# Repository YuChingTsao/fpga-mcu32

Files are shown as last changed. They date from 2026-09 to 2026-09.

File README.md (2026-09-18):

# FPGA MCU32 - AVR-Class Microcontroller on a DE10-Lite

A custom **32-bit fixed-cycle soft microcontroller implemented in VHDL** on an Intel MAX 10 FPGA. The design integrates a multi-cycle CPU, program/data memory, a memory-mapped bus, GPIO, timer, hardware PWM, prioritized interrupts, and dedicated timing/debug instrumentation.

**Capstone project - University of Windsor, Electrical & Computer Engineering (2026)**  
**Team:** Kazi Masrur Rahman and Yu Ching Tsao  
**Target hardware:** Terasic DE10-Lite / Intel MAX 10 (`10M50DAF484C7G`)

> The project uses an Arduino/ATmega328P-class board as a timing comparison baseline. “AVR-class” describes the embedded-control use case and comparison target; the custom MCU is not AVR instruction-set compatible.

## Project Highlights

- Designed a **32-bit multi-cycle CPU** with 16 general-purpose 32-bit registers and fixed 32-bit instructions.
- Built separate **1024 x 32-bit program ROM and data RAM** with a 32-bit memory-mapped interconnect.
- Implemented **GPIO, 32-bit timer, PWM, interrupt controller, and measurement/debug peripherals** in VHDL.
- Added self-checking verification across **18 VHDL testbenches**, from individual units through integrated CPU/peripheral behavior.
- Closed timing at **50 MHz** on the DE10-Lite with positive setup and hold slack.
- Measured an **FPGA request-to-GPIO response of 334 ns** using oscilloscope edge-crossing measurements.
- Demonstrated hardware PWM at **2.500 kHz and 25% duty cycle** using a 20,000-count period and 5,000-count duty setting.
- Exposed interrupt request, acknowledgement, ISR entry, PWM, and GPIO response through dedicated debug signals for Signal Tap and oscilloscope validation.

## Architecture

The system uses a Harvard-style memory organization and a common 32-bit memory-mapped peripheral bus.

| Block | Implementation |
|---|---|
| CPU | 32-bit multi-cycle FSM core |
| Register file | 16 x 32-bit registers |
| Instruction format | Fixed 32-bit |
| Program memory | 1024 x 32-bit ROM |
| Data memory | 1024 x 32-bit RAM |
| Bus | 32-bit memory-mapped interconnect |
| Peripherals | GPIO, timer, PWM, interrupt controller, measurement/debug |
| Clock | 50 MHz |
| FPGA | Intel MAX 10 on DE10-Lite |

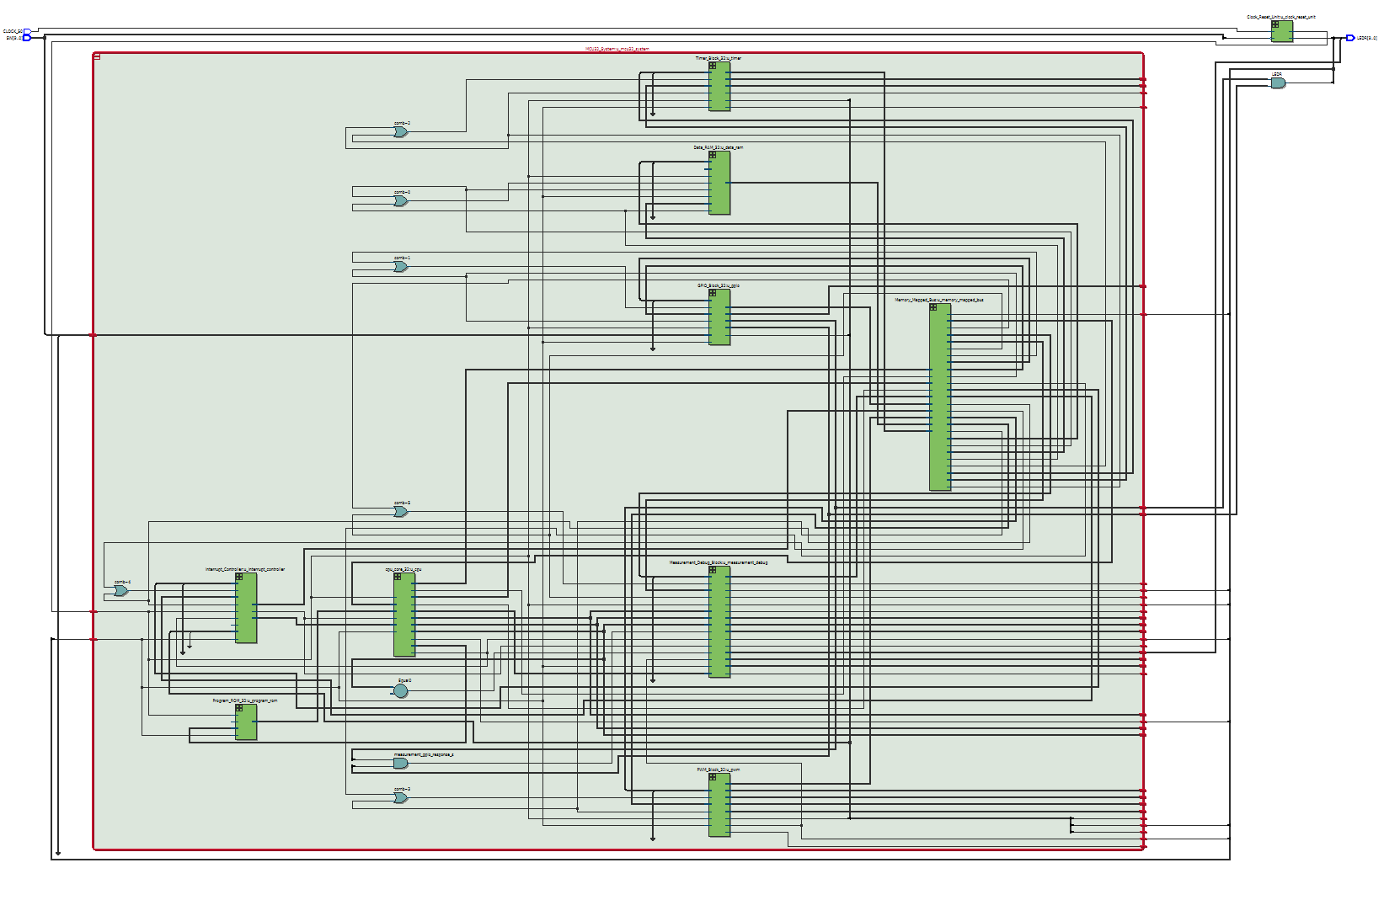
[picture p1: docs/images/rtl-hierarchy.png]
Quartus RTL hierarchy


## Memory Map

| Address range | Target |
|---|---|
| `0x00000000 - 0x00000FFF` | Data RAM |
| `0x40000000 - 0x4000001F` | GPIO |
| `0x40000020 - 0x4000003F` | Timer |
| `0x40000040 - 0x4000005F` | PWM |
| `0x40000060 - 0x4000007F` | Interrupt controller |
| `0x40000080 - 0x4000009F` | Measurement/debug |

Unmapped or invalid reads return `0xDEADBEEF` as a recognizable bus diagnostic value.

## Measured Results

### Interrupt response

The FPGA timing path was instrumented so the request and resulting GPIO response could be observed directly.

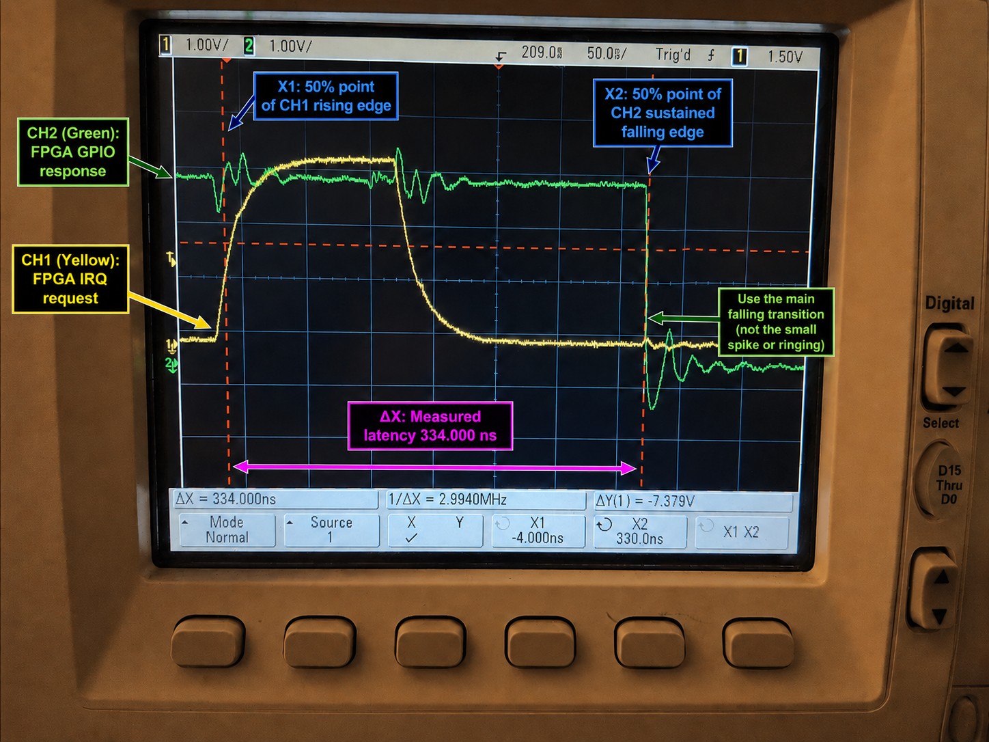
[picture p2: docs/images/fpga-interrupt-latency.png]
FPGA interrupt latency capture


Measured request-to-GPIO response: **334 ns**.

For the Arduino Nano-class comparison, the corresponding marker-to-ISR GPIO response capture measured **1.170 us** under the defined experiment endpoints.

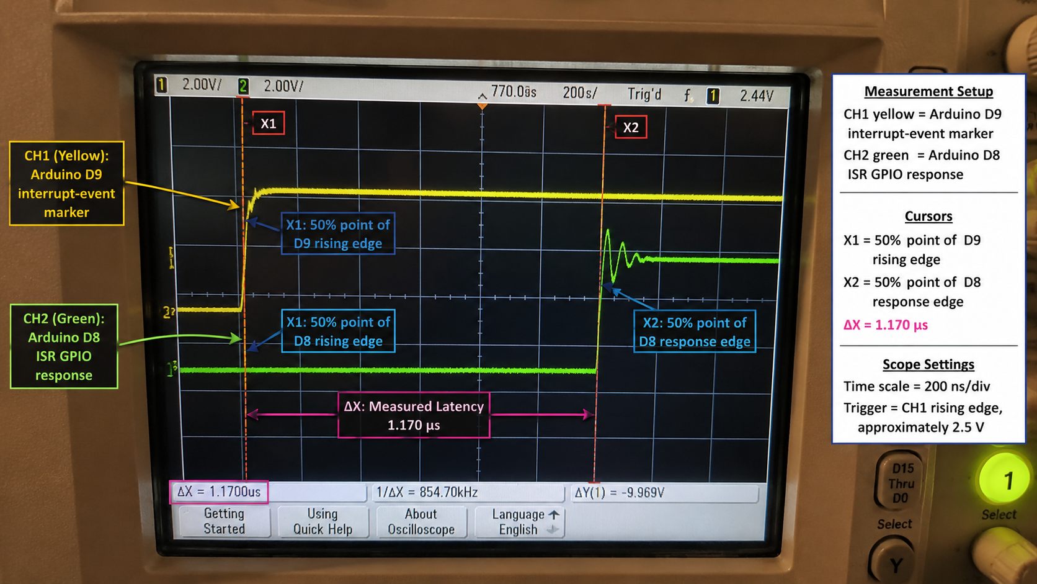
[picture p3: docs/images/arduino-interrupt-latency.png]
Arduino interrupt latency capture


The measurements use different internal visibility because the FPGA exposes controller-level events that are not externally accessible on the commercial MCU; the comparison is therefore presented as an experimental timing baseline rather than a universal platform-performance claim.

### PWM

The hardware PWM counter operates independently of CPU instruction execution. With a 50 MHz clock, `PERIOD = 20000` and `DUTY = 5000` produce a nominal 400 us period, 100 us high time, **2.500 kHz**, and **25% duty cycle**.

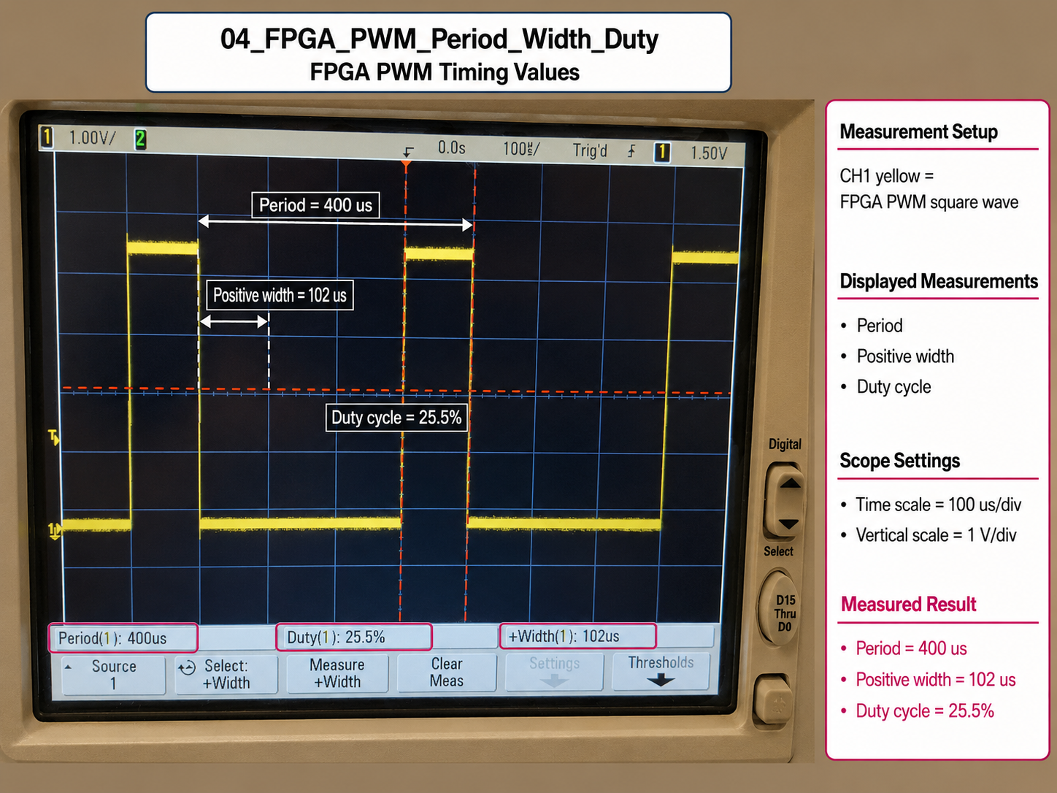
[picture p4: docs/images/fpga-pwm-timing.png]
FPGA PWM timing capture


## Verification

Verification was performed progressively:

1. Unit-level self-checking VHDL testbenches for the ALU, register file, memories, bus logic, GPIO, timer, PWM, interrupt controller, and measurement block.
2. CPU + memory and CPU + peripheral integration tests.
3. Full interrupt/ISR and firmware-driven system simulations.
4. Quartus synthesis, fitting, and static timing analysis at 50 MHz.
5. DE10-Lite LED-based hardware tests.
6. Intel Signal Tap observation of internal timing events.
7. Oscilloscope validation of interrupt response and PWM timing.

See [`docs/verification.md`](docs/verification.md) for the testbench inventory and validation flow.

## My Documented Contributions - Kazi Masrur Rahman

This was a two-person capstone project. My documented technical contributions included:

- Memory organization and the memory-mapped bus architecture.
- GPIO, timer, and PWM peripheral design/integration.
- Program/data memory integration and demonstration firmware configuration.
- DE10-Lite top-level integration, board I/O mapping, debug/probe outputs, and timing constraints.
- Shared work on interrupt/measurement integration and system-level validation.
- FPGA resource/timing analysis and laboratory measurement of interrupt/PWM behavior.
- Technical documentation and presentation of the implemented architecture and measured results.

The CPU core and other project elements were developed collaboratively with my teammate; this repository is presented as a portfolio record of the team project rather than as a claim of sole authorship.

## Repository Structure

```text
fpga-mcu32/
├── src/                  # Synthesizable VHDL
│   ├── bus/
│   ├── common/
│   ├── cpu/
│   ├── debug/
│   ├── memory/
│   ├── peripherals/
│   └── top/
├── testbench/            # Self-checking VHDL testbenches
├── quartus/              # Quartus project + timing constraints
├── debug/                # Signal Tap configurations
├── docs/                 # Architecture, verification, images, poster
└── scripts/              # Simulation helper
```

## Build in Quartus Prime

The original project was developed with **Quartus Prime 25.1 Standard**.

1. Clone the repository.
2. Open `quartus/MCU32_Project.qpf` in Quartus Prime.
3. Select the `top_level_de10_lite` revision if required.
4. Run **Analysis & Synthesis** or **Start Compilation**.
5. Program the DE10-Lite using the generated programming file.

The QSF references the VHDL source tree using paths relative to the `quartus/` directory, so the repository structure should be kept intact.

## Simulating with Questa / ModelSim

From the repository root, start Questa/ModelSim and run:

```tcl
do scripts/questa_compile.do
vsim work.tb_alu32
run -all
```

Replace `tb_alu32` with another entity from the `testbench/` directory. Integrated testbenches are listed in [`docs/verification.md`](docs/verification.md).

## Documentation

- [Architecture notes](docs/architecture.md)
- [Verification and validation](docs/verification.md)
- [Capstone poster](docs/poster/Team29_Poster.pdf)

## Tools & Skills Demonstrated

**VHDL · FPGA Design · Intel Quartus Prime · Questa/ModelSim · Digital Logic · Computer Architecture · Memory-Mapped I/O · Interrupts · PWM · Static Timing Analysis · Signal Tap · Oscilloscope Measurement · Hardware Verification**

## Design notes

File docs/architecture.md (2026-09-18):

# Architecture Notes

## CPU

The MCU32 processor is a custom 32-bit multi-cycle finite-state-machine CPU. Instructions move through explicit fetch, decode, execute, memory, and write-back states. Interrupt entry is accepted at instruction boundaries so the response path can be reasoned about and measured cycle-by-cycle.

The design uses 16 x 32-bit general-purpose registers, condition/status flags, a program counter, instruction register, saved return PC, and fixed 32-bit instructions.

## Memory Organization

Program and data storage are separated:

- Program ROM: 1024 x 32-bit words.
- Data RAM: 1024 x 32-bit words (4 KiB byte-addressed range).

This allows program fetches to remain separate from data/peripheral transactions.

## Memory-Mapped Interconnect

The 32-bit bus is split into one data-memory range and five peripheral windows. The interconnect contains:

- Address decoder.
- One-hot write-enable decoder.
- Read-data multiplexer.
- Default response / error handling.
- Word-alignment checking.

Invalid or unmapped reads return `0xDEADBEEF`.

## Peripherals

### GPIO

Provides synchronized input sampling, direction/output registers, rising/falling edge detection, interrupt enables, and sticky interrupt status.

### Timer

A 32-bit counter with prescaler, compare, control, and status registers. Compare and overflow events can generate interrupt requests.

### PWM

A dedicated hardware counter produces PWM independently of CPU execution. The demonstration configuration uses a 20,000-count period and 5,000-count high interval at 50 MHz.

### Interrupt Controller

Four sources are synchronized and edge-captured into pending bits. A fixed-priority policy selects the active source and produces a vector address. The controller exposes status and debug information to software and the measurement subsystem.

### Measurement / Debug

Dedicated counters and probe signals expose interrupt request, acknowledgement, ISR entry, GPIO response, and PWM timing. These signals were used in simulation, Signal Tap, and oscilloscope measurements.

## Board Integration

The top level maps the design to the DE10-Lite's 50 MHz clock, switches, red LEDs, and GPIO expansion pins. External switch inputs are synchronized internally. Timing constraints exclude asynchronous observation/input paths while constraining the internal 50 MHz clocked design.

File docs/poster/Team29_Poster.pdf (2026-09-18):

# Team 29: Design and Implementation of an AVR-Class Microcontroller on an FPGA

Commercial microcontrollers are inexpensive and easy to program, but their internal real-time timing path is largely fixed by the vendor. This project develops a 32-bit fixed-cycle microcontroller in VHDL for the DE10-Lite FPGA. The design combines a multi-cycle finite-state machine, sixteen 32-bit registers, fixed 32-bit instructions, separate program and data memories, and a 32-bit memory-mapped bus. GPIO, a 32-bit timer, hardware PWM, and a prioritized interrupt controller are integrated as on-chip peripherals. Dedicated probe pins expose interrupt request, acknowledge, ISR entry, GPIO response, and PWM timing. The contribution is a transparent and measurable real-time control platform rather than a claim that FPGAs are universally superior to MCUs.

### Department: Electrical and Computer Engineering Capstone 2026

### Kazi Masrur Rahman and Yu Ching Tsao Advisor: Dr. Roberto Muscedere

### INTRODUCTION & OBJECTIVE

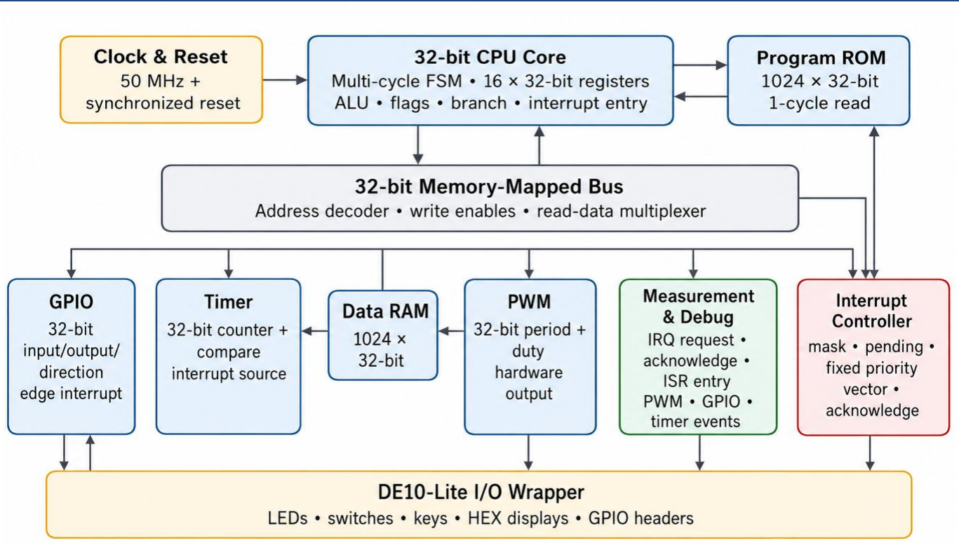
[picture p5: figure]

### METHODOLOGY

### INTERRUPT TIMING TRACE

ABSTRACT | DESIGN OVERVIEW | RESULTS & TIMING COMPARISON

A soft-core processor is described in hardware description language, customized for an application, and synthesized into programmable logic [1]. This makes the complete control path visible from the register-transfer level to a physical output pin. The project asks whether a deliberately simple FPGA microcontroller can provide a shorter, bounded, and easier-toaudit request-to-response path than an Arduino Nano-class MCU while remaining understandable to students. Objective: Design, simulate, implement, and measure the FPGA MCU, then compare its digital I/O timing with an ATmega328P-class system using identical trigger and response definitions.

### Implementation and Comparison Platform

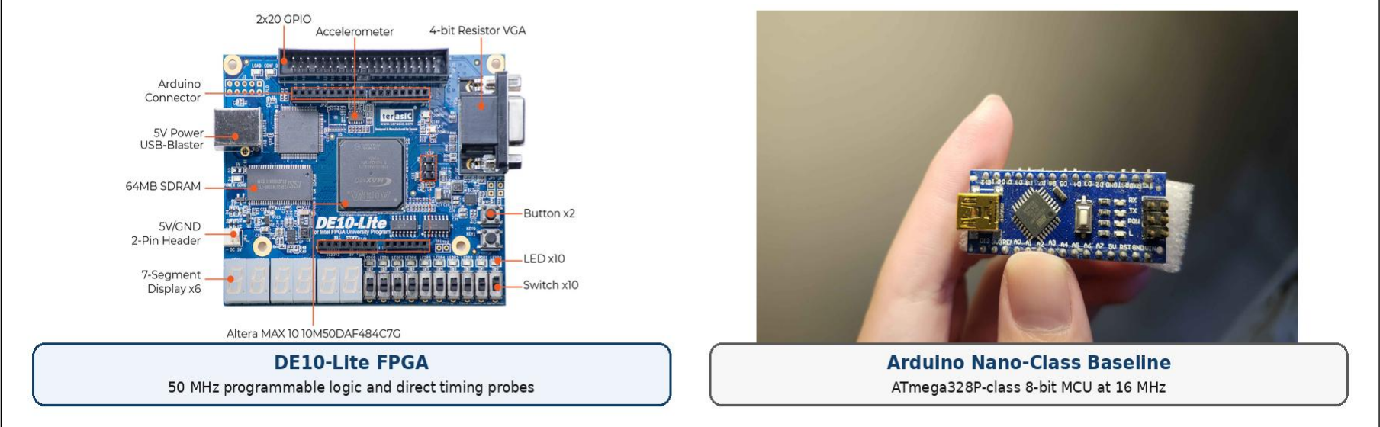
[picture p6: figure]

### DELIVERABLES

Figure 1: DE10-Lite implementation platform and Arduino Nano-class comparison baseline

- 32-bit multi-cycle CPU with a fixed 32-bit instruction format.
- Sixteen 32-bit general-purpose registers and Z/N/C/V/I status flags.
- Separate 1024 × 32-bit program ROM and data RAM.
- Memory-mapped GPIO, timer, PWM, and prioritized interrupt controller.
- Self-checking VHDL testbenches, RTL Viewer diagrams, and timing constraints.
- Signal Tap and oscilloscope probes for interrupt latency and PWM verification.

The CPU executes each instruction through explicit fetch, decode, execute, memory, and writeback states. A fixedpriority interrupt controller records pending sources, applies masks, selects a vector, and acknowledges service. GPIO, timer, PWM, interrupt, and debug registers share one fixed-cycle 32-bit memory-mapped bus. The PWM counter runs independently of firmware, reducing output jitter.

### SYSTEM ARCHITECTURE

Figure 2: Top-level FPGA MCU architecture and memory-mapped peripheral structure.

Development follows a simulation-first sequence. Clock/reset, ALU, register file, CPU, ROM, RAM, GPIO, timer, PWM, interrupts, and measurement logic are verified independently before full-system integration. The final design is synthesized in Quartus, constrained for 50 MHz, programmed through the USB-Blaster, observed in Signal Tap, and tested with the same oscilloscope event definition used for the Arduino.

### Implementation & Verification Flow

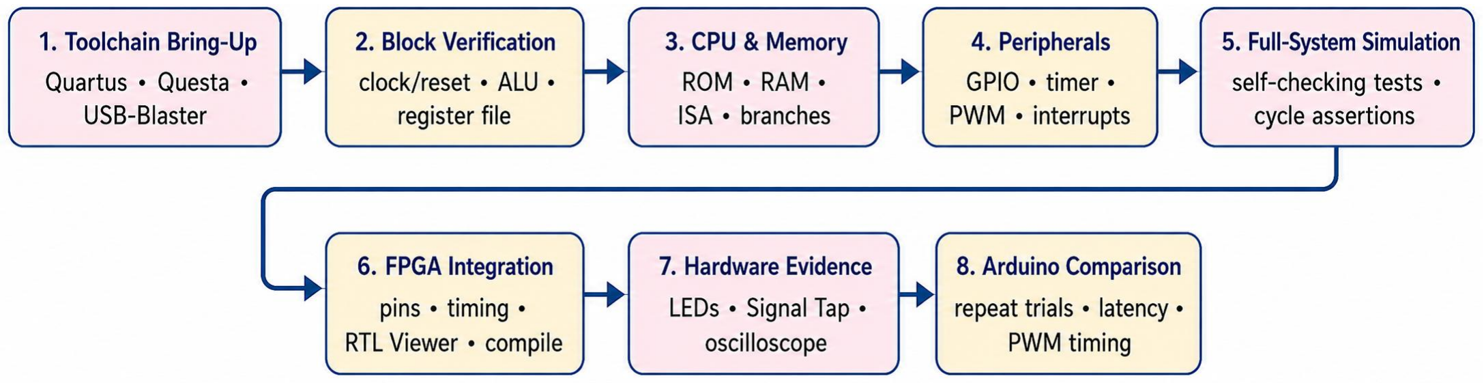
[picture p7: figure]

Figure 3: Block-by-block verification, FPGA integration, and hardware comparison workflow

### ARCHITECTURE

At 50 MHz, each clock cycle is 20 ns. The FPGA uses 3–5 cycles for normal instructions and up to 8 cycles for interrupt entry, giving delays of 60–160 ns. Including two synchronizer stages, the external-pin-to-ISR bound is 200 ns. The ATmega328P requires a 4-cycle interrupt response followed by a 3-cycle vector jump [2], totaling at least 437.5 ns at 16 MHz before the first handler instruction. Therefore, the FPGA target is approximately 2.2× faster.

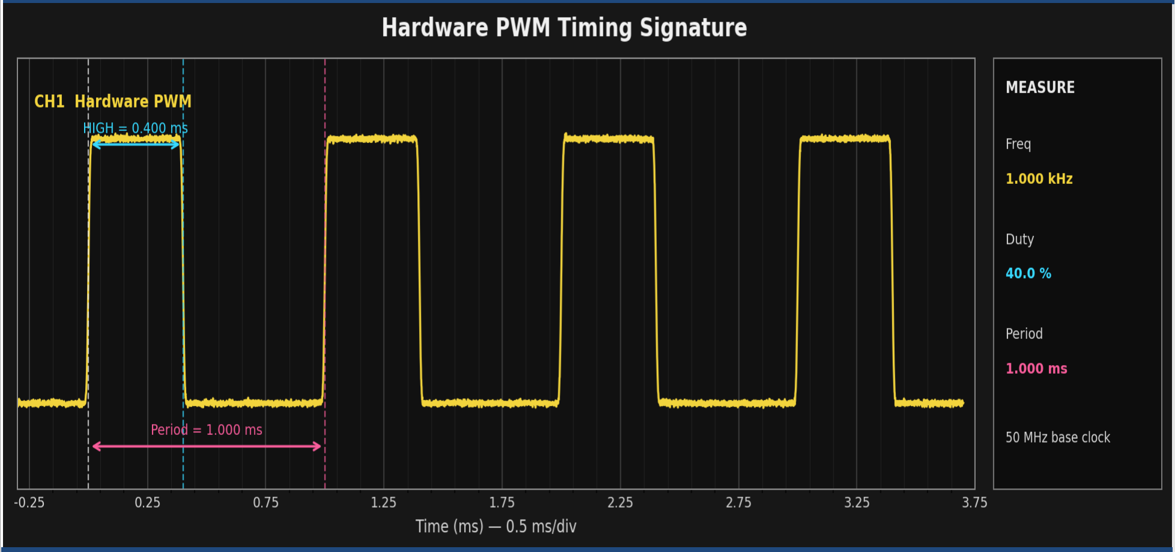
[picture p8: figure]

TIMING SUMMARY

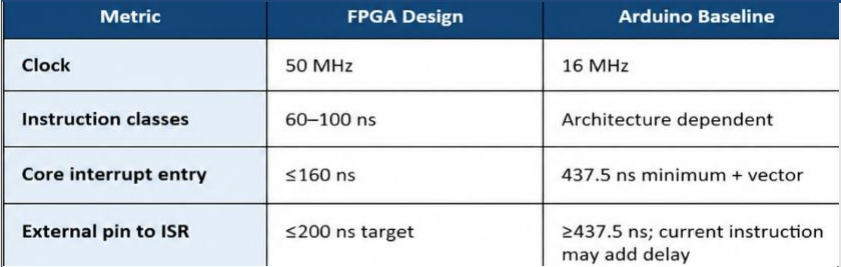
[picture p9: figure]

### CONCLUSION & FUTURE WORK

The project presents a 32-bit FPGA soft microcontroller with fixed-cycle execution, memory-mapped peripherals, hardware PWM, prioritized interrupts, and timing probes. Its clear timing behavior can be simulated, measured, and modified. Future work includes improved hardware testing, software tools, communication interfaces, expanded PWM and interrupt features, and comparison with a pipelined core.

### ACKNOWLEDGEMENT & REFERENCES

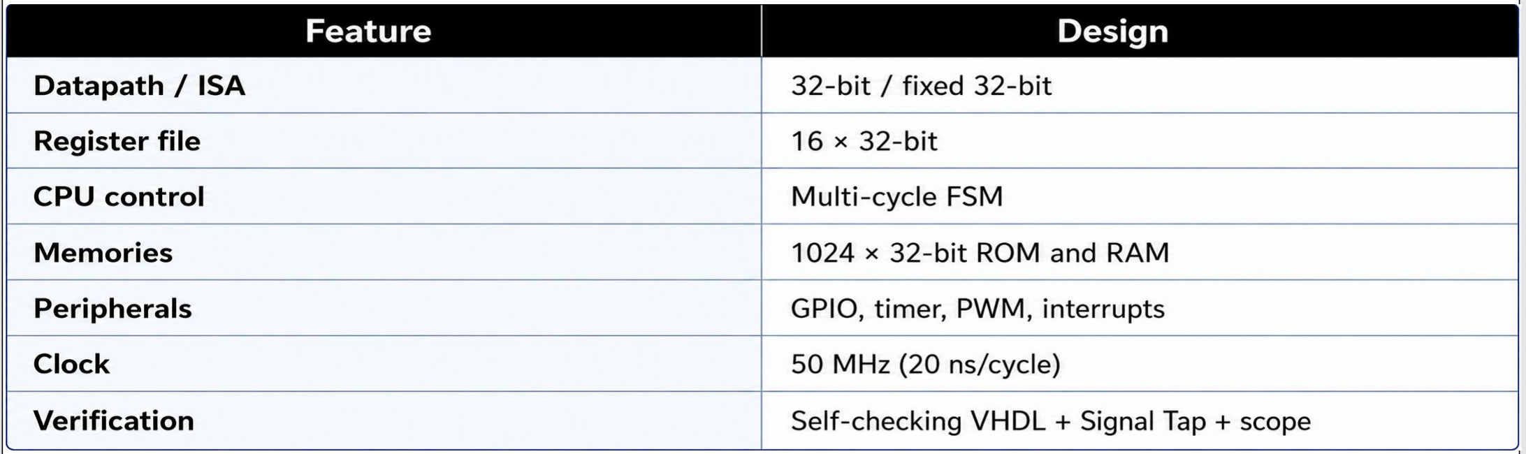
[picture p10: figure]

We would like to thank Dr. Roberto Muscedere and our colleague Abdullah Mohammed Ali for their guidance and support.
[1] J. G. Tong, I. D. L. Anderson, and M. A. S. Khalid, “Soft-Core Processors for Embedded Systems,” ICM, 2006. [2] Microchip Technology, ATmega328P Data Sheet, Sec. 6.7.1.
[3] Terasic Technologies, DE10-Lite User Manual.

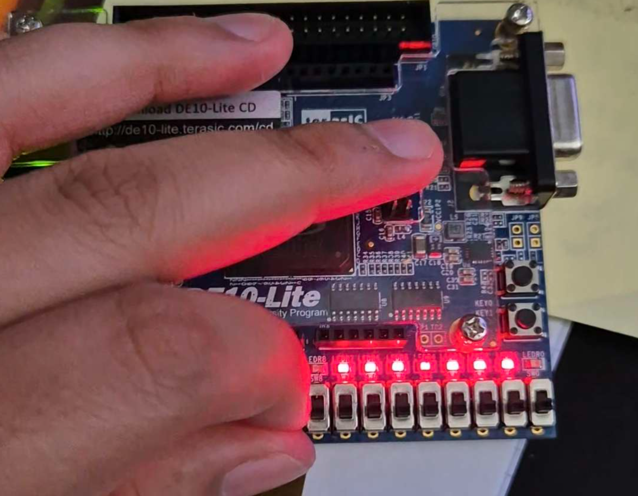
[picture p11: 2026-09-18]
docs/images/de10-lite-hardware.png

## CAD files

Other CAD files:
debug/Interrupt_Capture.stp
debug/PWM_Capture.stp

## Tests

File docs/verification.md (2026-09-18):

# Verification and Validation

The project followed a simulation-first verification flow before board-level measurement.

## Testbench Inventory

### Unit tests

- `tb_alu32.vhd`
- `tb_register_file_16x32.vhd`
- `tb_Clock_Reset_Unit.vhd`
- `tb_Program_ROM_32.vhd`
- `tb_Data_RAM_32.vhd`
- `tb_memory_mapped_bus.vhd`
- `tb_GPIO_Block_32.vhd`
- `tb_Timer_Block_32.vhd`
- `tb_PWM_Block_32.vhd`
- `tb_Interrupt_Controller.vhd`
- `tb_Measurement_Debug_Block.vhd`

### CPU / integration tests

- `tb_cpu_core_32.vhd`
- `tb_CPU_ROM_RAM_32.vhd`
- `tb_CPU_Program_ROM_32.vhd`
- `tb_CPU_Bus_GPIO_32.vhd`
- `tb_CPU_Bus_Timer_32.vhd`
- `tb_CPU_Bus_PWM_32.vhd`
- `tb_CPU_Interrupt_ISR_32.vhd`

## Hardware Validation Flow

1. Compile and simulate individual blocks.
2. Integrate CPU, memories, bus, and peripherals.
3. Run firmware-driven system simulations.
4. Synthesize and fit for the Intel MAX 10 target.
5. Verify static timing at 50 MHz.
6. Validate GPIO/timer/PWM behavior using DE10-Lite LEDs.
7. Observe internal events using Signal Tap.
8. Route timing signals to GPIO probe pins and measure with an oscilloscope.

## Final Implementation Results

- Target clock: **50 MHz** (`20 ns` period).
- Logic elements: **34,808 / 49,760 (70%)**.
- Dedicated registers: **27,531 / 49,760 (55%)**.
- I/O pins: **26 / 360 (7%)**.
- Setup slack: **+2.767 ns**.
- Hold slack: **+0.237 ns**.
- Total negative slack: **0.000 ns**.
- Measured FPGA request-to-GPIO response: **334 ns**.
- Measured PWM: **2.500 kHz**, nominal **25% duty cycle**.

## Scope of the Timing Comparison

The FPGA implementation exposes intermediate controller and ISR-entry events directly, while the commercial Arduino/ATmega328P-class comparison cannot expose the same internal nodes. The oscilloscope comparison therefore uses explicitly defined external measurement endpoints and should be interpreted as an experimental baseline, not as a universal FPGA-vs-MCU performance claim.
